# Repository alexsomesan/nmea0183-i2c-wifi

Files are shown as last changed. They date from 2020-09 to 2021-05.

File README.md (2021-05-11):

# NMEA0183 WiFi bridge for NASA Clipper Wind instrument

Reads wind data from a NASA Clipper wind instrument via I2C and sends out NMEA0183 wind messages via WiFi.

# Hardware needed

At the very minimum, a prototype can be assembled with just an ESP32 dev board and a 5 pin DIN plug, by connecting the I2C and power lines from the connector directly to the board. The NASA unit output 5V level I2c, but ESP32 is 5V tolerrant so a level converter is not mandatory (still nice though).

[TODO: add pinnout diagram]

```
ESP32         < --- >  NASA 5 Pin DIN connector
-----------------------------------------------
GPIO21 (SDA)  < --- >  PIN 3
GPIO22 (SCL)  < --- >  PIN 1
GND           < --- >  PIN 2
```

The hardware folder contains an untested design (KiCAD 5) for an integrted board with power regulators and level shifters, which should give the most robust solution.

# Installation

To build the code, you need to install the official Espressif SDK, as explained here: https://docs.espressif.com/projects/esp-idf/en/latest/esp32/get-started/#installation-step-by-step

With the ESP-IDF successfully installed, connect the ESP32 board via USB and flash it with the following command:
```
idf.py partition_table-flash flash
```

Once that completes without erros, the board is ready to use. You need to connect it to a WiFi network (e.g. and OpenPlotter WiFi network).

To setup wifi, the board starts it's own WiFi network called "nasa-clipper-wind". Connect to that and wait for the login pop-up to show up. In the pop-up window you will be able to browse available networks and connect to the network of your choice. Once setup, the board will remember this network and connect to it on startup.

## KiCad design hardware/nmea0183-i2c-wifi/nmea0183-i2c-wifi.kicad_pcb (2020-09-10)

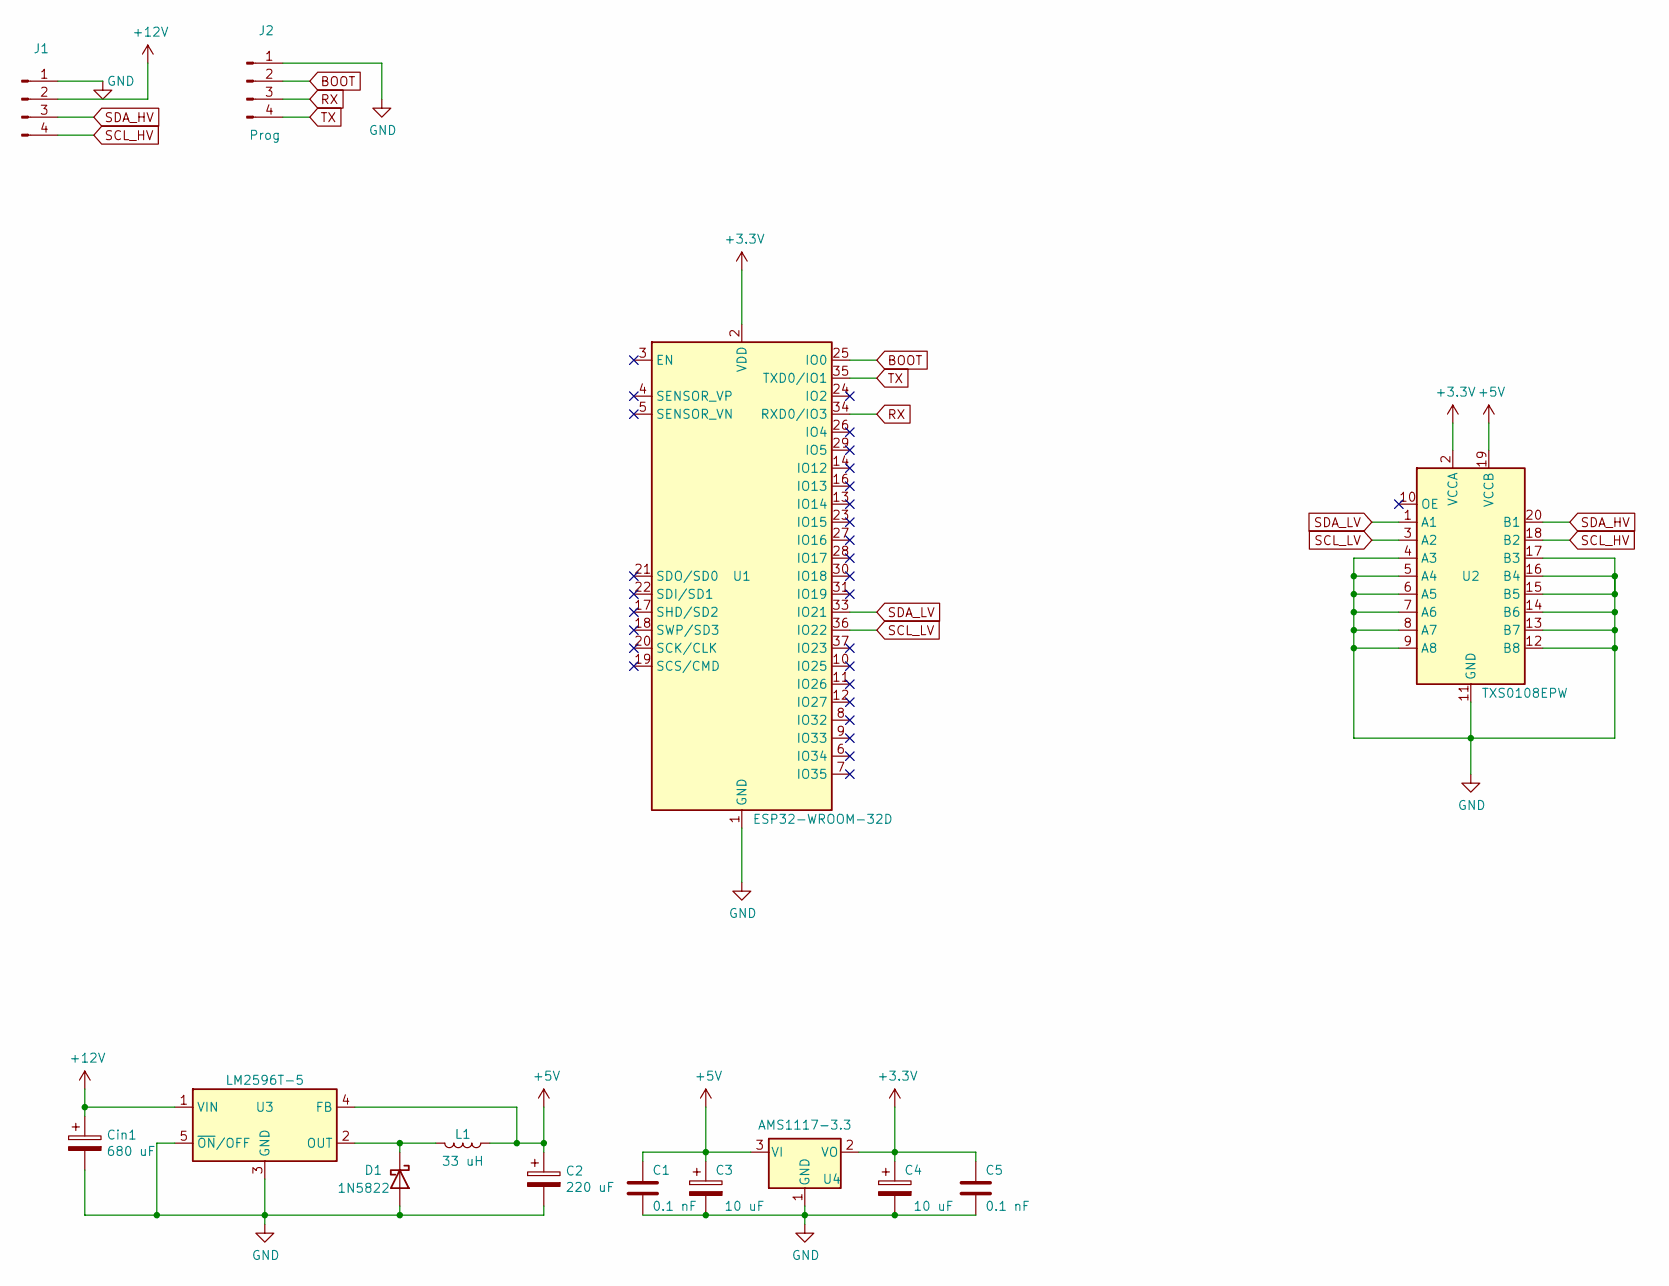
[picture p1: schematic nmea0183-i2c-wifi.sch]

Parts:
C1, C5: 0.1 nF; C_0805_2012Metric
C2: 220 uF; CP_Radial_D6.3mm_P2.50mm
C3, C4: 10 uF; CP_Radial_D4.0mm_P2.00mm
Cin1: 680 uF; CP_Radial_D10.0mm_P5.00mm
D1: 1N5822; D_DO-201AD_P15.24mm_Horizontal
J1: Conn_01x04_Male; JST_XH_B4B-XH-AM_1x04_P2.50mm_Vertical
J2: Prog; PinHeader_1x04_P2.54mm_Vertical
L1: 33 uH; L_Radial_D9.5mm_P5.00mm_Fastron_07HVP
U1: ESP32-WROOM-32D; ESP32-WROOM-32
U2: TXS0108EPW; TSSOP-20_4.4x6.5mm_P0.65mm
U3: LM2596T-5; TO-220-5_P3.4x3.7mm_StaggerOdd_Lead3.8mm_Vertical
U4: AMS1117-3.3; SOT-223-3_TabPin2

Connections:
+3V3: C4.1, C5.1, U1.2 (VDD), U2.2 (VCCA), U4.2 (VO)
+5V: C1.1, C2.1, C3.1, L1.1, U2.19 (VCCB), U3.4 (FB), U4.3 (VI)
+12V: Cin1.1, J1.2, U3.1 (VIN)
BOOT: J2.2, U1.25 (IO0)
GND: C1.2, C2.2, C3.2, C4.2, C5.2, Cin1.2, D1.2 (A), J1.1, J2.1, U1.1 (GND), U1.15 (GND), U1.38 (GND), U1.39 (GND), U2.4 (A3), U2.5 (A4), U2.6 (A5), U2.7 (A6), U2.8 (A7), U2.9 (A8), U2.11 (GND), U2.12 (B8), U2.13 (B7), U2.14 (B6), U2.15 (B5), U2.16 (B4), U2.17 (B3), U3.3 (GND), U3.5 (~ON~/OFF), U4.1 (GND)
unnamed: D1.1 (K), L1.2, U3.2 (OUT)
RX: J2.3, U1.34 (RXD0/IO3)
SCL_HV: J1.4, U2.18 (B2)
SCL_LV: U1.36 (IO22), U2.3 (A2)
SDA_HV: J1.3, U2.20 (B1)
SDA_LV: U1.33 (IO21), U2.1 (A1)
TX: J2.4, U1.35 (TXD0/IO1)

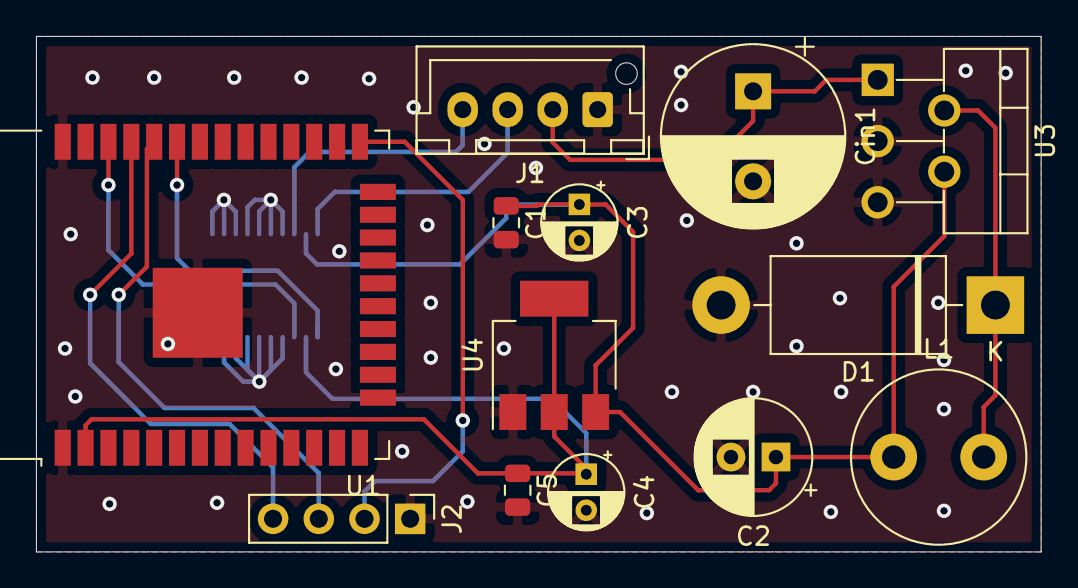
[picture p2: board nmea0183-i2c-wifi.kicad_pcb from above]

Board: 2 copper layers, 55.8 x 28.6 mm, 14 parts (1 on the bottom side), 12 nets.

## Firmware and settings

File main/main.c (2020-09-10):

#include "freertos/FreeRTOS.h"
#include "freertos/task.h"
#include "freertos/queue.h"
#include "freertos/event_groups.h"
#include "esp_system.h"
#include "esp_wifi.h"
#include "esp_event.h"
#include "esp_log.h"
#include "wifi_manager.h"

#include "http_hook.h"
#include "i2ctask.h"
#include "nmea.h"

#define NMEA_QUEUE_DEPTH 50

const char *TAG = "nmea0183-wifi-i2c";
uint networkOn = 0;

esp_err_t my_custom_handler(httpd_req_t *);
void cb_connection_ok(void *);

void app_main() {
    TaskHandle_t xI2CReceiveHandle = NULL;
    TaskHandle_t xNMEASenderHandle = NULL;

    QueueHandle_t xNMEAQueue = xQueueCreate(
        NMEA_QUEUE_DEPTH, 
        sizeof(char) * SENT_BUF_SZ
    );
    
    wifi_manager_start();
    wifi_manager_set_callback(WM_EVENT_STA_GOT_IP, &cb_connection_ok);
    
    // http_app_set_handler_hook(HTTP_GET, &my_custom_handler);

    while(networkOn == 0) {
        vTaskDelay(portTICK_PERIOD_MS);
    }

    xTaskCreate(vTaskI2CReceive, "I2C-RECEIVER", 2048, 
        xNMEAQueue, tskIDLE_PRIORITY, &xI2CReceiveHandle);

    configASSERT( xI2CReceiveHandle );

    
    xTaskCreate(vTaskNMEASend, "NMEA-SENDER", 2048, 
        xNMEAQueue, tskIDLE_PRIORITY, &xNMEASenderHandle);

    configASSERT( xNMEASenderHandle );

    for(;;) {
        vTaskDelay(portTICK_PERIOD_MS);
    }
    ESP_LOGE(TAG, "END OF MAIN");
}

void cb_connection_ok(void *p) {
	ESP_LOGI(TAG, "I have a connection!");
    networkOn = 1;
}

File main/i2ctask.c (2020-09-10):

#include "stdio.h"
#include "esp_log.h"
#include "driver/i2c.h"
#include "sdkconfig.h"
#include "string.h"
#include "freertos/FreeRTOS.h"
#include "freertos/task.h"
#include "freertos/queue.h"
#include "i2ctask.h"

extern const char *TAG;

static void i2c_slave_init(void) {
    i2c_config_t i2cSlave;

    i2cSlave.mode = I2C_MODE_SLAVE;
    i2cSlave.slave.slave_addr = I2C_ADDR;
    i2cSlave.slave.addr_10bit_en = 0;
    i2cSlave.scl_io_num = I2C_SCL_PIN;
    i2cSlave.sda_io_num = I2C_SDA_PIN;
    i2cSlave.sda_pullup_en = GPIO_PULLUP_DISABLE;
    i2cSlave.scl_pullup_en = GPIO_PULLUP_DISABLE;
    
    if (i2c_param_config(I2C_NUM_0, &i2cSlave) != ESP_OK) {
        ESP_LOGE(TAG, "Failed to configure I2C slave.\n");
    }
    if (i2c_driver_install(I2C_NUM_0, I2C_MODE_SLAVE, I2C_SLAVE_RX_BUF_LEN, I2C_SLAVE_TX_BUF_LEN, 0) != ESP_OK) {
        ESP_LOGE(TAG, "Failed to install I2C driver.\n");
    }
    if (i2c_reset_rx_fifo(I2C_NUM_0) != ESP_OK) {
        ESP_LOGE(TAG, "Failed to reset I2C EX FIFO.\n");
    }
    if (i2c_reset_rx_fifo(I2C_NUM_0) != ESP_OK) {
        ESP_LOGE(TAG, "Failed to reset I2C RX FIFO.\n");
    }
    if (i2c_reset_tx_fifo(I2C_NUM_0) != ESP_OK) {
        ESP_LOGE(TAG, "Failed to reset I2C TX FIFO.\n");
    }
    if (i2c_filter_enable(I2C_NUM_0, 6)  != ESP_OK) {
        ESP_LOGE(TAG, "Failed to I2C SCL filtering.\n");
    }
    ESP_LOGI(TAG, "I2C slave started.\n");
}

uint8_t getChecksum(char* str)
{
    uint8_t cs = 0;
    for (unsigned int n = 1; n < strlen(str) - 1; n++) {
        cs ^= str[n];
    }
    return cs;
}

char* NMEA0183WindSentence(char* buf, uint16_t dir, uint mph) {
    memset(buf, 0, SENT_BUF_SZ);
    sprintf(buf, "$WIMWV,%d,R,%.1f,N,A*", dir, mph / 1.15f / 10);
    uint8_t cs = getChecksum(buf);
    sprintf(buf + strlen(buf), "%02X\r\n", cs);
    return buf;
}

void vTaskI2CReceive( void * xQueue ) {
    QueueHandle_t xNMEAQueue = (QueueHandle_t)xQueue;

    char nmeastr[SENT_BUF_SZ];
    uint8_t i2cdata[5];

    i2c_slave_init();

    while(1) {
        int i2cLen= i2c_slave_read_buffer(I2C_NUM_0, i2cdata, 5, 1000 / portTICK_PERIOD_MS);
        if (i2cLen == ESP_FAIL) {
            ESP_LOGE(TAG, "Failed to read from I2C!");
            continue;
        }
        if (i2cLen != 5) {
            ESP_LOGI(TAG, "Inconsistent I2C read: %d bytes, not 5", i2cLen);
            continue;
        }
        NMEA0183WindSentence(nmeastr, 
        (uint16_t)(i2cdata[0] << 8 | i2cdata[1]),
        i2cdata[3]);
        if (xQueueGenericSend(xNMEAQueue, nmeastr, 10 / portTICK_PERIOD_MS, queueSEND_TO_BACK) != pdPASS) {
            ESP_LOGE(TAG, "Failed to queue up NMEA message");
        }
    }
}

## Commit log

2020-09-10 Initial working prototype - RTOS tasks for reading I2C and printing NMEA to log.
2020-09-10 Minimal hardware board
    [nmea0183-i2c-wifi.kicad_pcb, nmea0183-i2c-wifi.sch]
